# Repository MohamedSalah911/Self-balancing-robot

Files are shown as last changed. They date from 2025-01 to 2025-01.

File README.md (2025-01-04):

# Two-Wheeled Self-Balancing Robot  

This repository contains all the resources, code, and documentation for a **two-wheeled self-balancing robot** developed as part of our controls and measurements course project. The goal of the project is to design, simulate, and eventually build a robot capable of maintaining balance using control systems.  

---

## **Table of Contents**  
1. [Project Overview](#project-overview)  
2. [Features](#features)  
3. [Getting Started](#getting-started)  
4. [Folder Structure](#folder-structure)  
5. [Simulation Tools](#simulation-tools)  
6. [Future Work](#future-work)  
7. [Team Members](#team-members) 

---

## **Project Overview**  
A self-balancing robot is a fundamental example of applying control systems theory to a real-world problem. This project explores the design and implementation of a control strategy to stabilize the robot's upright position using sensors and actuators.  

### **Key Objectives:**  
- Simulate the dynamic behavior of the robot.  
- Design and implement a control system (PID).  
- Explore sensor fusion and motor control techniques.  
- Use ROS for advanced functionalities and potential real-world testing (planned).  

---

## **Features**  
- **MATLAB Simulink Model:** Simulates the robot's dynamics and control response.  
- **PID Controller Implementation:** Ensures stability and balance.  
- **ROS Integration:** Facilitates sensor data handling and communication.  
- **Hardware Design:** Basic layout constructed on TinkerCAD for proof of concept.  

---

## **Folder Structure**  
```plaintext  
self-balancing-robot/  
│
├── main.ino               # Main code used in the microcontroller
├── Self_balance.slx       # MATLAB Simscape files and ROS configuration scripts
├── Report.pdf             # A report to document all steps done in project.
├── design/                # Contains TinkerCAD layouts and physical design resources  
├── libraries/             # Libraries used to help with communication with other components 
└── README.md              # Project overview and usage information  
```  

---

## **Simulation Tools**  
- **MATLAB Simulink:** For dynamic modeling and control design.  
- **ROS (Planned):** For advanced sensor and actuator control. 

---

## **Future Work**  
- Implement the project in ROS for advanced tasks. 
- Implement advanced control strategies, such as LQR or Kalman filters. 

---

## **Team Members**  
- Mohamed Salah  
- Marwan Yousry
- Ahmed Ghazal
- Mazen Mahmoud
- Karim Ibrahim
- Mohamed Hassan
- Mohamed Alaa
- Ahmed Khaled
- Mohamed Hosny 

---

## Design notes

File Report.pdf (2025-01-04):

# Self-balancing robot

### احمد شريف احمد غزال 21010095 مازن محمود شعبان محمد 21011036 كريم إبراهيم محمد 21010972 مروان يسري محمود 21011314 محمد صالح مختار ابراهيم 21011159 احمد خالد سعد الدين مصطفى 21010069 محمد عالء محى الدين 21011193 محمد حسني محمود ابوالعنين 21011118

### محمد حسن عبدالشهيد عبدللا 20011541

## Introduction:

Self-balancing robots represent a remarkable intersection of engineering disciplines, including electronics, mechanics, and control systems. Inspired by the principles of inverted pendulum dynamics, these robots remain upright by continuously adjusting their orientation through feedback control mechanisms. This capability demonstrates the practical implementation of core principles in robotics, such as stability, motion control, and sensor integration.
The objective of this project is to design and develop a self-balancing robot that can maintain its equilibrium on two wheels. This requires a careful combination of hardware components like sensors, actuators, and microcontrollers, as well as software algorithms for real-time data processing and control. Central to the operation of such a robot is the use of feedback control systems, specifically Proportional-Integral-Derivative (PID) controllers, to process data from gyroscopes and accelerometers, ensuring precise balance and movement.
In addition to demonstrating fundamental engineering principles, self-balancing robots have broader applications, including in personal transport devices, autonomous delivery systems, and humanoid robotics. The project also provides a platform to explore the challenges of integrating software with hardware and optimizing performance under dynamic conditions.
This report details the design, implementation, and testing of a self-balancing robot. It discusses the theoretical framework, hardware configuration, software architecture, and experimental results, highlighting the key challenges encountered and solutions developed.

## components:

- Arduino uno

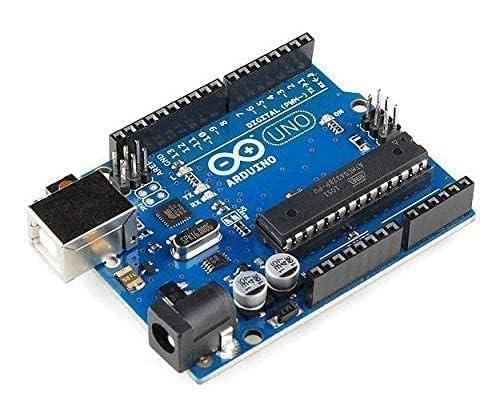
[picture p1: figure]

- IMU (MPU6050)

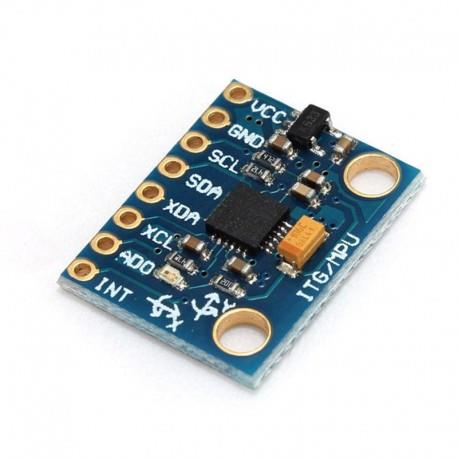
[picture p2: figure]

- (DC motors) x 2

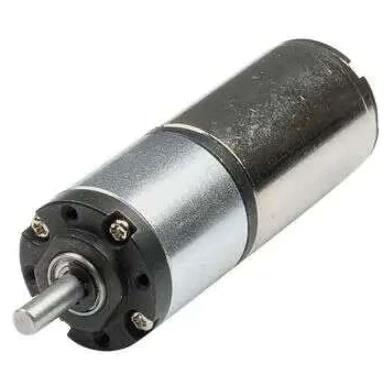
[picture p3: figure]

- Motor driver (L298)

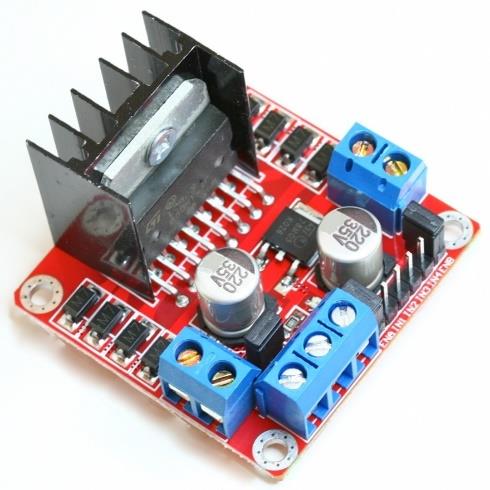
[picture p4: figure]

- (Batteries) x 3

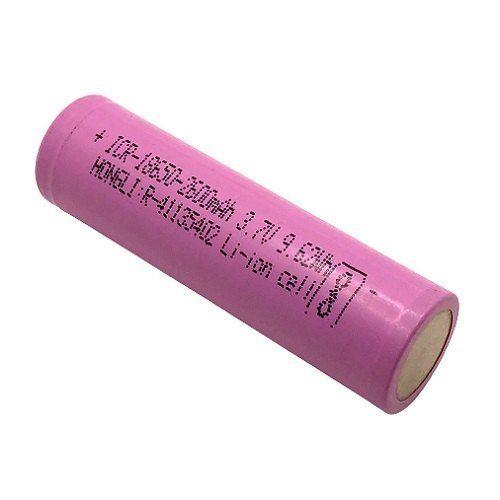
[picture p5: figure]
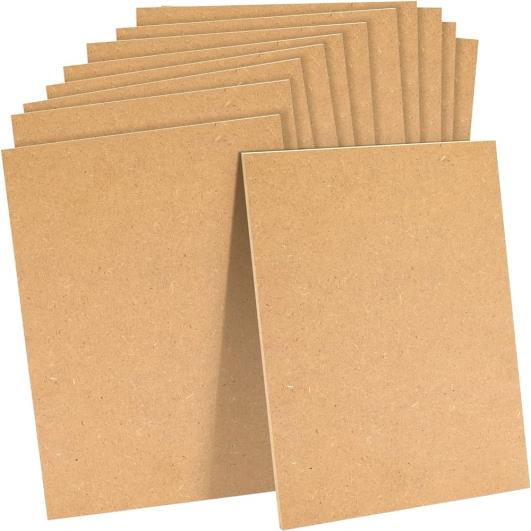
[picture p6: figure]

- wooden sheets for the body

## Mechanical design:

Design#1

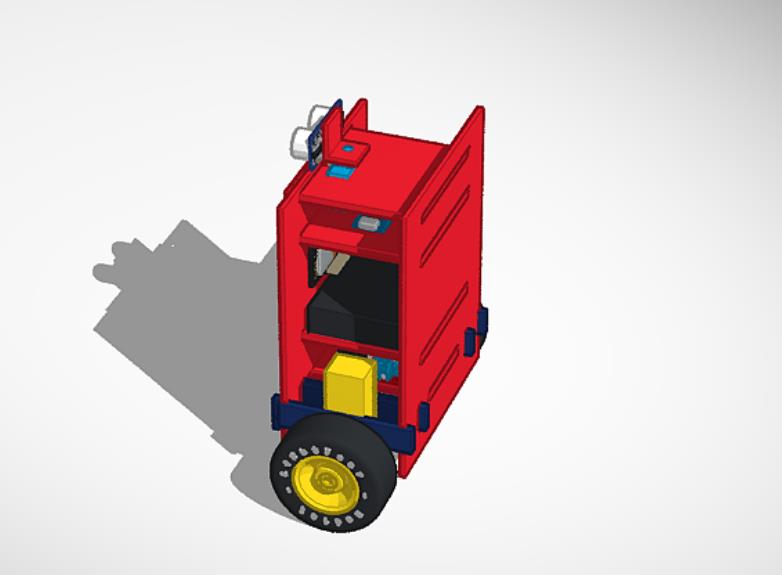
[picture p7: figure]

This design faced two significant challenges. The first was the robot's height, which made maintaining balance more difficult due to the higher center of gravity. The second challenge was the initial choice of motors, which lacked the necessary power to support the robot's weight effectively, leading to suboptimal performance.

Design#2

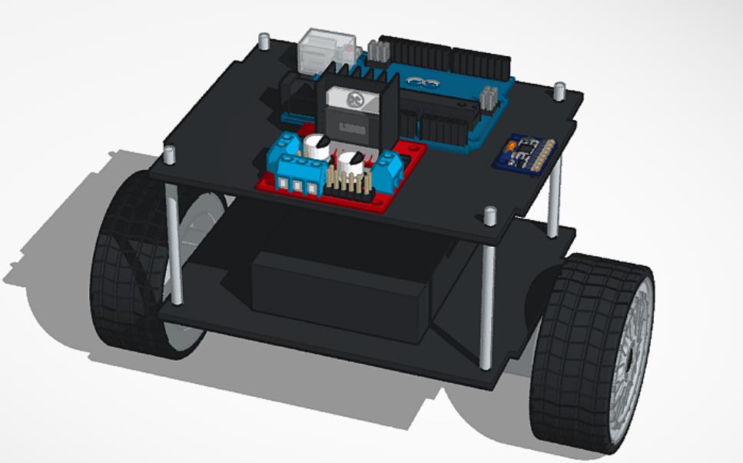
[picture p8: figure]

In the second design, we addressed stability issues by making the robot shorter and wider, which lowered its center of gravity and improved its ability to balance. We also replaced the original motors with more powerful ones, ensuring they could handle the robot’s weight effectively and deliver optimal performance.

## Simulation:

We utilized MATLAB Simscape to simulate and analyze the robot's physical performance, allowing us to evaluate its behavior and optimize the design before physical implementation.

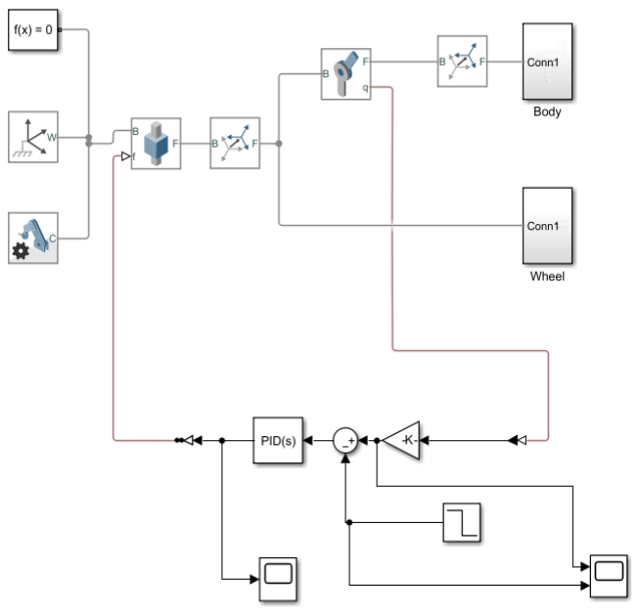
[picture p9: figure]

- Simscape model:

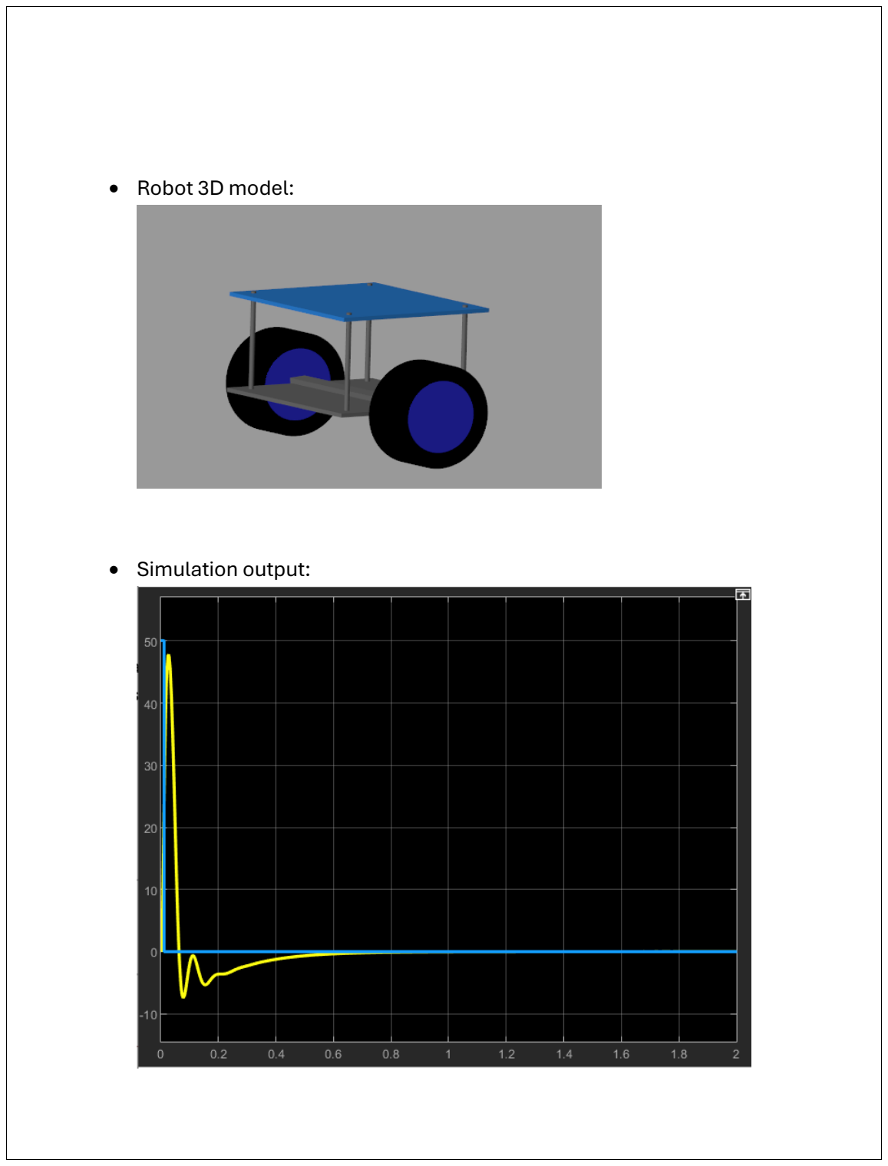
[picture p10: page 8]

- Robot 3D model:
- Simulation output:

## Software implementation:

We used the MPU6050 sensor to accurately measure the pitch angle of the robot, providing real-time data on its orientation. To maintain the robot in an upright position, we designed a PID controller that dynamically adjusts the motor speeds based on the sensor readings. This control system ensures that the robot remains balanced by continuously correcting deviations from its vertical alignment.

For the tuning process, we began with the initial PID values obtained from the simulation as a starting point. These values were then refined through a trialand-error approach, adjusting them incrementally while closely observing the system's response. This iterative method allowed us to optimize the controller settings and achieve the best performance for maintaining the robot's balance.

## Bill of materials:

Arduino uno | 400 LE
IMU (MPU6050) | 125 LE
(DC motors) x 2 | 700 LE
Motor driver (L298) | 80 LE
(Batteries) x 3 | 100 LE
Robot body | 541 LE
Total | 1946 LE

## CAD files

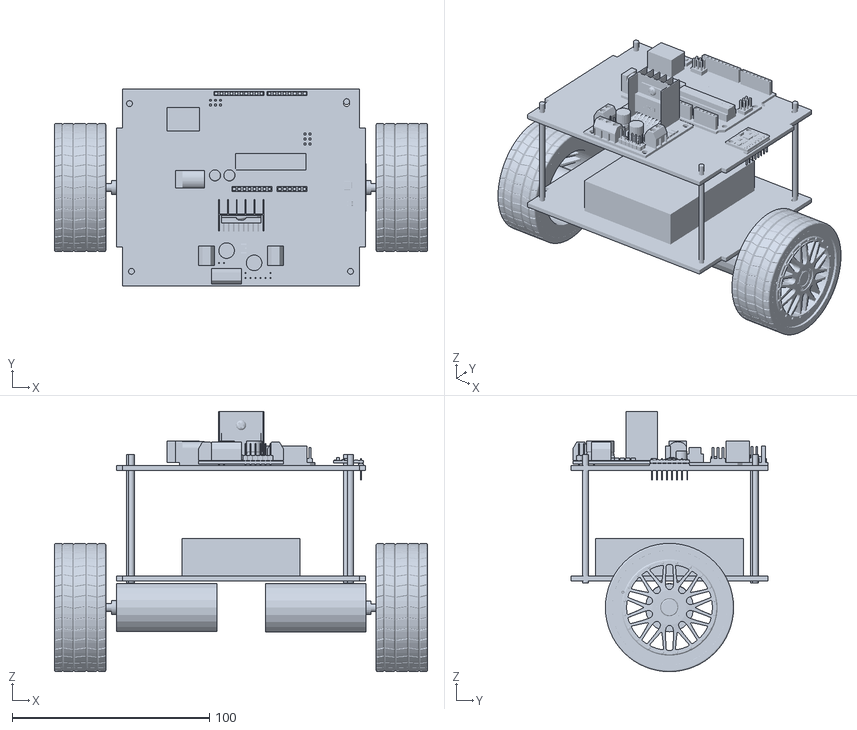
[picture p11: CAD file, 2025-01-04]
design/new-design.stl
189.0 x 100.0 x 131.9

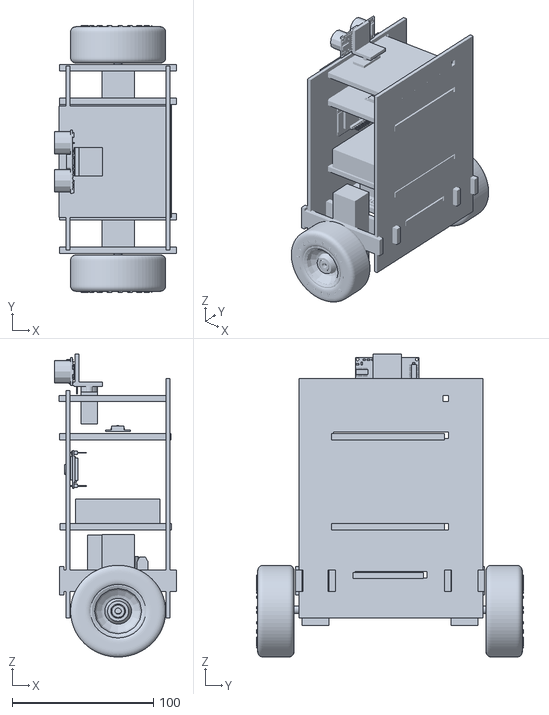
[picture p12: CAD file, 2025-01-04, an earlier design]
design/old-design.stl
86.6 x 189.0 x 214.8

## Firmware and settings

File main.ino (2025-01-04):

#include <PID_v1.h>
#include <LMotorController.h>
#include "I2Cdev.h"
#include "MPU6050_6Axis_MotionApps20.h"

#if I2CDEV_IMPLEMENTATION == I2CDEV_ARDUINO_WIRE
    #include "Wire.h"
#endif

#define MIN_ABS_SPEED 80
#define MAX_TURN_SPEED 150 // Cap the turning speed
#define OBSTACLE_DISTANCE 20 // Minimum distance to detect obstacle (in cm)
#define TURN_EXTENSION_DURATION 70 // Extra time (ms) to keep turning after avoiding obstacle
#define SPEED_RAMP_STEP 20 // Step size to increase/decrease speed
#define SPEED_RAMP_INTERVAL 50 // Interval (ms) for speed ramping
#define OBSTACLE_COOLDOWN 500 // Cooldown period after turning (in ms)

// Ultrasonic Sensor Pins
#define trigPin 3
#define echoPin 2

MPU6050 mpu;

bool dmpReady = false;
uint8_t devStatus;
uint16_t packetSize;
uint16_t fifoCount;
uint8_t fifoBuffer[64];

Quaternion q;
VectorFloat gravity;
float ypr[3];        

// PID
double setpoint = 0; // Initial setpoint
double input, output;
double Kp = 4;
double Kd = 0.4; 
double Ki = 105;
PID pid(&input, &output, &setpoint, Kp, Ki, Kd, DIRECT);

double motorSpeedFactorLeft = 0.5;
double motorSpeedFactorRight = 0.5;

int ENA = 10;
int IN1 = 5;
int IN2 = 4;
int IN3 = 7;
int IN4 = 6;
int ENB = 11;
LMotorController motorController(ENA, IN1, IN2, ENB, IN3, IN4, motorSpeedFactorLeft, motorSpeedFactorRight);

volatile unsigned long echoStartTime = 0;
volatile unsigned long echoEndTime = 0;
volatile bool measuringDistance = false;

bool turningLeft = false;         // Track if turning left
bool rampingSpeed = false;        // Track if ramping speed after turning
unsigned long turnStartTime = 0; // Track when turning started
unsigned long lastObstacleTime = 0; // Time of the last obstacle encounter

double currentSpeed = MIN_ABS_SPEED; // Current speed for ramping
unsigned long lastSpeedUpdateTime = 0; // Last time speed was updated for ramping

void triggerUltrasonic() {
    if (!measuringDistance) {
        digitalWrite(trigPin, LOW);
        delayMicroseconds(2);
        digitalWrite(trigPin, HIGH);
        delayMicroseconds(10);
        digitalWrite(trigPin, LOW);
        measuringDistance = true;
        echoStartTime = micros();
    }
}

float getDistance() {
    if (measuringDistance && echoEndTime > echoStartTime) {
        unsigned long duration = echoEndTime - echoStartTime;
        measuringDistance = false; // Reset for next measurement
        return (duration * 0.034) / 2.0;
    }
    return -1; // Distance not ready
}

void echoISR() {
    if (digitalRead(echoPin) == HIGH) {
        echoStartTime = micros();
    } else {
        echoEndTime = micros();
    }
}

void setup() {
    pinMode(trigPin, OUTPUT);
    pinMode(echoPin, INPUT);
    attachInterrupt(digitalPinToInterrupt(echoPin), echoISR, CHANGE);

    #if I2CDEV_IMPLEMENTATION == I2CDEV_ARDUINO_WIRE
        Wire.begin();
        TWBR = 24;
    #elif I2CDEV_IMPLEMENTATION == I2CDEV_BUILTIN_FASTWIRE
        Fastwire::setup(400, true);
    #endif

    Serial.begin(115200);
    while (!Serial);

    Serial.println(F("Initializing I2C devices..."));
    mpu.initialize();

    Serial.println(F("Testing device connections..."));
    Serial.println(mpu.testConnection() ? F("MPU6050 connection successful") : F("MPU6050 connection failed"));

    Serial.println(F("Initializing DMP..."));
    devStatus = mpu.dmpInitialize();

    // MPU-6050 Calibration offsets
    mpu.setXGyroOffset(46);
    mpu.setYGyroOffset(15);
    mpu.setZGyroOffset(32);
    mpu.setXAccelOffset(-1462);
    mpu.setYAccelOffset(226);
    mpu.setZAccelOffset(1781);

    if (devStatus == 0) {
        Serial.println(F("Enabling DMP..."));
        mpu.setDMPEnabled(true);

        Serial.println(F("DMP ready!"));
        dmpReady = true;

        packetSize = mpu.dmpGetFIFOPacketSize();

        pid.SetMode(AUTOMATIC);
        pid.SetSampleTime(10);
        pid.SetOutputLimits(-255, 255);
    } else {
        Serial.print(F("DMP Initialization failed (code "));
        Serial.print(devStatus);
        Serial.println(F(")"));
    }
}

void rampSpeed(double targetSpeed) {
    unsigned long currentTime = millis();
    if (currentTime - lastSpeedUpdateTime >= SPEED_RAMP_INTERVAL) {
        if (currentSpeed < targetSpeed) {
            currentSpeed = min(currentSpeed + SPEED_RAMP_STEP, targetSpeed);
        } else if (currentSpeed > targetSpeed) {
            currentSpeed = max(currentSpeed - SPEED_RAMP_STEP, targetSpeed);
        }
        lastSpeedUpdateTime = currentTime;

        if (currentSpeed == targetSpeed) {
            rampingSpeed = false; // Stop ramping once the target speed is reached
        }
    }
}

void loop() {
    if (!dmpReady) return;

    fifoCount = mpu.getFIFOCount();

    if (fifoCount >= packetSize) {
        mpu.getFIFOBytes(fifoBuffer, packetSize);
        mpu.dmpGetQuaternion(&q, fifoBuffer);
        mpu.dmpGetGravity(&gravity, &q);
        mpu.dmpGetYawPitchRoll(ypr, &q, &gravity);
        double input = ypr[2] * 180 * 1.6 / M_PI;
        pid.Compute();

        // Non-blocking ultrasonic distance measurement
        triggerUltrasonic();
        float distance = getDistance();

        // Obstacle avoidance logic
        if (distance > 0) { // Valid distance measurement
            Serial.print("Distance: ");
            Serial.println(distance);

            if (distance < OBSTACLE_DISTANCE && millis() - lastObstacleTime > OBSTACLE_COOLDOWN) {
                turningLeft = true;                // Start turning
                rampingSpeed = false;              // Disable ramping during turning
                currentSpeed = MIN_ABS_SPEED;      // Reset speed to minimum
                lastObstacleTime = millis();       // Record time of obstacle detection
                turnStartTime = millis();          // Record start time of turn
                Serial.println("Obstacle detected! Starting turn left.");
            }
        }

        // Continue turning with balancing
        if (turningLeft) {
            if (millis() - turnStartTime <= TURN_EXTENSION_DURATION) {
                motorController.turnLeft(MAX_TURN_SPEED, false); 
                Serial.println("Turning left.");
                return; // Skip normal movement while turning
            } else {
                turningLeft = false; // Stop turning after extension
                rampingSpeed = true; // Enable ramping after turning
                Serial.println("Turning complete. Resuming normal operation.");
            }
        }

        // Ramping speed after turning
        if (rampingSpeed) {
            rampSpeed(MIN_ABS_SPEED + abs(output));
        }

        // Normal balancing or movement
        motorController.move(output, rampingSpeed ? currentSpeed : MIN_ABS_SPEED + abs(output));

        // Debugging
        Serial.print("Setpoint: "); Serial.print(setpoint); Serial.print(" | ");
        Serial.print("PID Output: "); Serial.print(output); Serial.print(" | ");
        Serial.print("Current Speed: "); Serial.println(currentSpeed);
    }
}

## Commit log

2025-01-03 Update main.ino
    added object avoidance while self-balancing in the same position
    [main.ino]
2025-01-04 added design's files for 3d or 2d printing
    [new-design.stl, old-design.stl]
